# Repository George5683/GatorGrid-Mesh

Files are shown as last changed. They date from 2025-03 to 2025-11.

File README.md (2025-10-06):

# GatorGrid

GatorGrid is a multifunctional software solution designed for the Raspberry Pi Pico W by UF students to create a mesh network with wireless communication. It provides a low-cost, open-source alternative to existing mesh network solutions like ESP-WIFI-MESH and Zigbee by enabling seamless Wi-Fi-based communication between multiple nodes. The design uses two Pico W's per node in the network The project aims to ensure reliable message relay, even in case of node failures, making it ideal for individuals and organizations needing decentralized communication in remote or disaster-affected areas. GatorGrid focuses on accessibility, scalability, and real-time data transmission.

## Features
- MeshNode library for STA and AP mode
- Doxygen for documentation
- SPI interaction for internode communication
- Kicad Custom PCB deisgn with external battery charging capabilities

## Requirements to run
- Install doxygen
- Install graphviz
- Install extensions for VS code if applicable: Doxygen Documentation Generator 

## How to run Doxygen
1. Use doxygen Doxyfile to generate the documentation
2. Use **start doc\html\index.html** (WINDOWS ONLY) or **open doc/html/index.html** (LINUX/MAC)

## How to upload code to PICO W's
1. Push the bootsel and plug the microcontroller into the computer
2. Create the .uf2 file and upload it to PICO W by dragging it into the directory

## Bugs:
- At the moment if in an environment with high congestion, packets may not arrive. Moving locations is required.
- SPI has a slight delay of 110 ms per message sent. 

## Author
George Salomon, Cole Smith, Jonathon Brown, Mateo Slivka, Maxwell Evans

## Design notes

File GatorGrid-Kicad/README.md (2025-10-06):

## Kicad Designs

Design are separated into versions based on functionality and Design stages 

*Starting from BETA BUILD the first design V(X.0) is always the dev kit with extra Pico pinouts sockets for monitoring*

# Kicad Stages      
- INITIAL BUILD (V0.1 & V1.0)
- ALPHA BUILD (V2.0+)
- BETA BUILD (V3.0+)
- FINAL BUILD (V4.0+)

# External Sensor
At the moment the external sensor list is limited but can be expanded as needed
- DHT11 external PCB extension

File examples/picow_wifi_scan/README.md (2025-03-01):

# Driver Embedded Lab

This project integrates the LIS3DH accelerometer with a NeoMatrix LED display on a Raspberry Pi Pico W. It reads acceleration data and visually represents the movement using LEDs along with indicating when level.

## Features
- Reads acceleration data from the LIS3DH sensor.
- Controls a NeoMatrix LED display 
- Level program

## Run
1. Unzip the folder:
   ```sh
   unzip level.zip
   ```
2. Change the directory to the driver folder:
    ```sh
   cd /driver
   ```
3. Build the project using CMake:
    ```sh
   mkdir build && cd build
   cmake ..
   make
   ```
4. Flash the compiled binary to the Raspberry Pi Pico W.

## Functions Overview

### **LIS3DH**

### `LIS3DH()`
Constructor that initializes the x, y, and z values to 0

### `init()`
Initializes the accelerometer.

### `set_reg(uint8_t reg, uint8_t val)`
Set a register to a specific value

### `read_reg(uint8_t reg)`
read a register and output the value

### `update()`
Updates the x, y, and z values in the class with the accelerometer values.

### **NeoMatrix**

### `NeoMatrix(uint8_t width, uint8_t height)`
Constructor to set the width and height of the matrix

### `init()`
Initialize the NeoMatrix to get ready to shine

### `set_pixel(uint8_t row, uint8_t col, uint32_t color)`
set a pixel, within the 2D vector buffer in the class, to a specific color

### `clear_pixels()`
clear the pixels in the buffer

### `write()`
write the buffer data to the Matrix

### `urgb_u32(uint8_t r, uint8_t g, uint8_t b)`
Helper function to convert the values to a 32 bit value

## Author
George Salomon

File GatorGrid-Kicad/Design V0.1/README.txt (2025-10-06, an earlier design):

## Kicad Design V0.1
Explanation for the Pinouts on the Pico W:

- GPIO 1-22 and 26-28 are as the schematic states
- VBUS is 5V when connected to micro usb to power the Pico
- VSYS can power the Pico with ~1.8-5.5V input

TIPS:
- For adding a secondary power source, you need a schottky diode on the VSYS

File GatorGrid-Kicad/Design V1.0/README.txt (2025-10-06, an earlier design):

# Kicad Design V1.0

## Explanation for the Pinouts on the Pico W:

- GPIO 1-22 and 26-28 are as the schematic states
- VBUS is 5V when connected to micro usb to power the Pico
- VSYS can power the Pico with ~1.8-5.5V input

## Schematic Update:
- Added a JST connector for an extenal battery to be connected
- Added a switch after the JSt conncector for powering the Picos
- Added a polyfuse (polyfuse's reset instead of replacing the fuse if its broken)
- Added a Schottky diode (to prevent current backflow and if user connects the battery backwards)
- Added a charging/safety cicuit [TP4056] (for charging the battery and battery management)

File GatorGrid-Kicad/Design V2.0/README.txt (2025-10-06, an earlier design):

# Kicad Design V2.0

## Explanation for the Pinouts on the Pico W:

- GPIO 1-22 and 26-28 are as the schematic states
- VBUS is 5V when connected to micro usb to power the Pico
- VSYS can power the Pico with ~1.8-5.5V input

## Schematic Update:
- Fixed wiring of temp on the TP4056 as it was disconnected which casued the battery to not charge. 
- Changed POWER LED to be driven by two transistors which allows it to turn on when both picos are on. 
- Removed the schottky diode connected to the battery and instead put a diode on each VSYS out from each pico in order to prevent backflow when eitehr are plugged in as VSYS can be input and output. 
- Reworked Wiring on PCB

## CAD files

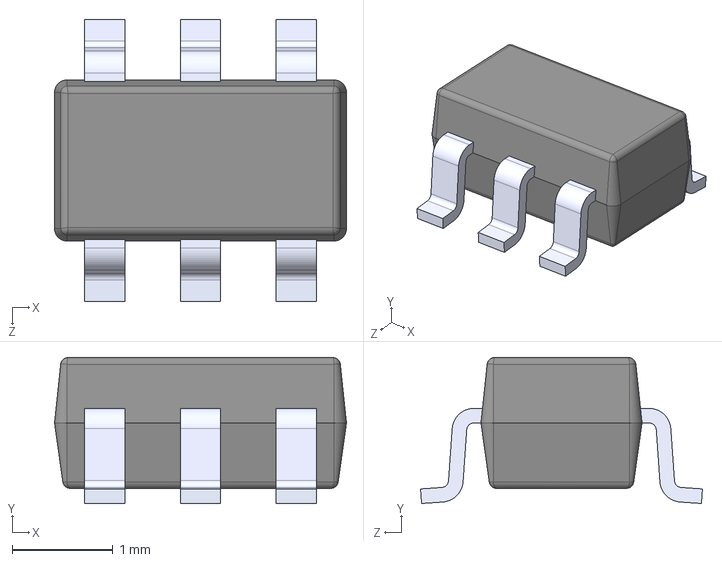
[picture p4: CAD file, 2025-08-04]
GatorGrid-Kicad/Design V4.0/Resources/MT3608/MT3608.step
2.90 x 1.45 x 2.80 mm

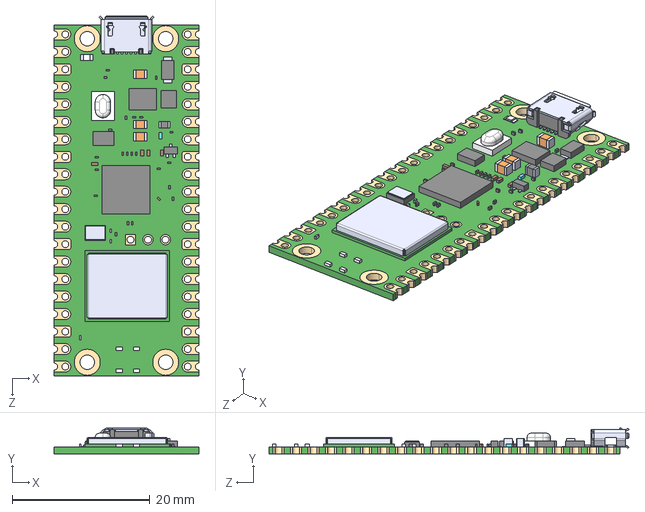
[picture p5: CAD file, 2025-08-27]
GatorGrid-Kicad/Design V4.0/Resources/RASPBERRY_PI_PICO_W(NH)/RASPBERRY_PI_PICO_W.step
21.0 x 3.73 x 52.3 mm

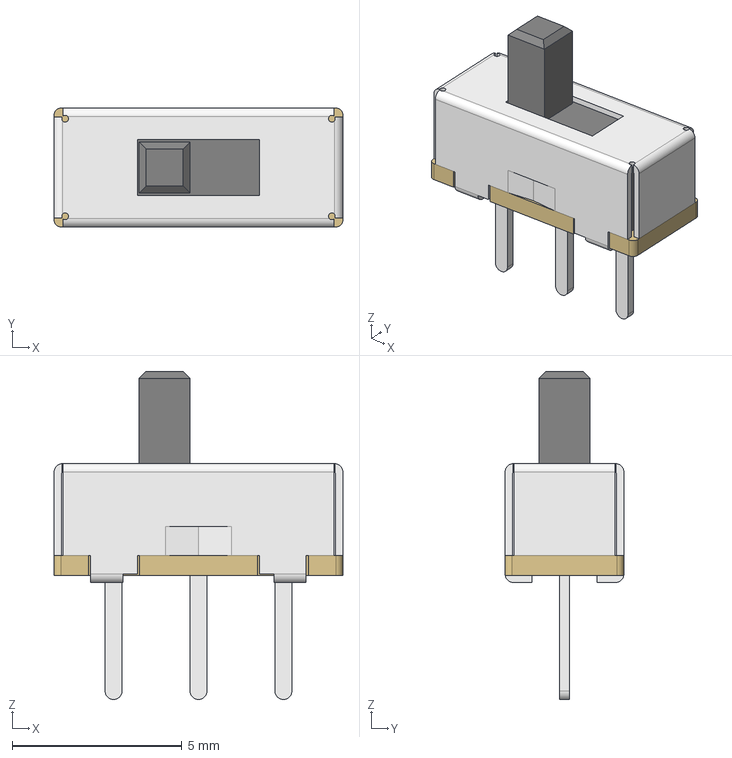
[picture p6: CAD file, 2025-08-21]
GatorGrid-Kicad/Design V4.0/Resources/SS12D00/SPDT slide switch SS12D00.step
8.50 x 3.50 x 9.66 mm

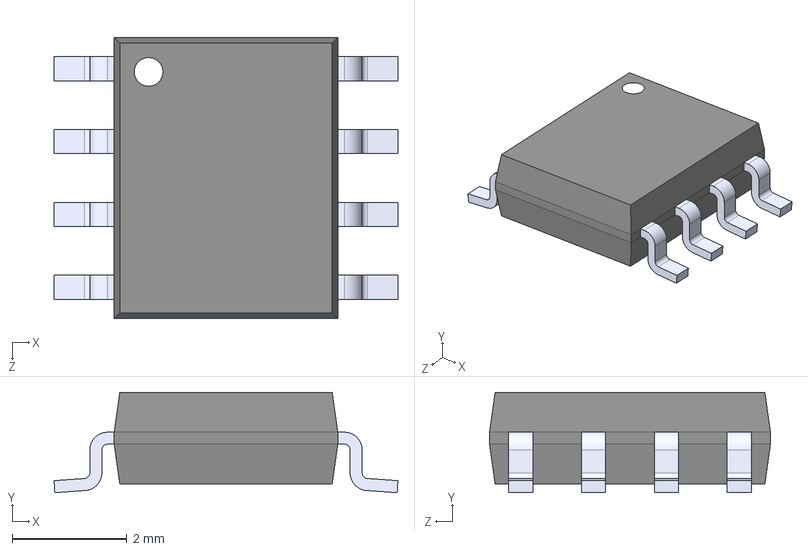
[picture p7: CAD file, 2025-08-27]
GatorGrid-Kicad/Design V4.0/Resources/TP4056/TP4056.step
6.00 x 1.75 x 4.90 mm

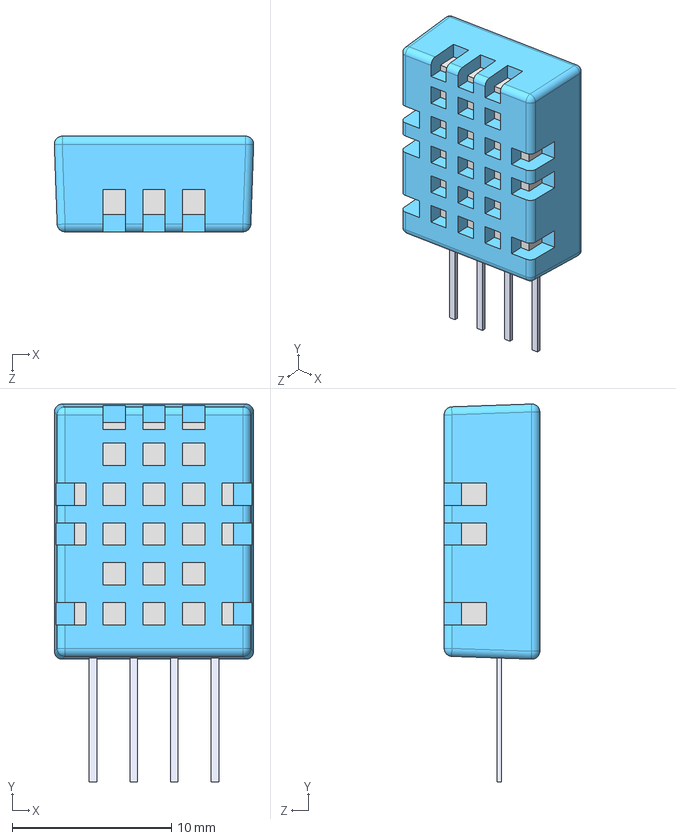
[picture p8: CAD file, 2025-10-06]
GatorGrid-Kicad/External-Sensor/Resources/DHT11/DHT11.step
12.5 x 23.7 x 6.00 mm

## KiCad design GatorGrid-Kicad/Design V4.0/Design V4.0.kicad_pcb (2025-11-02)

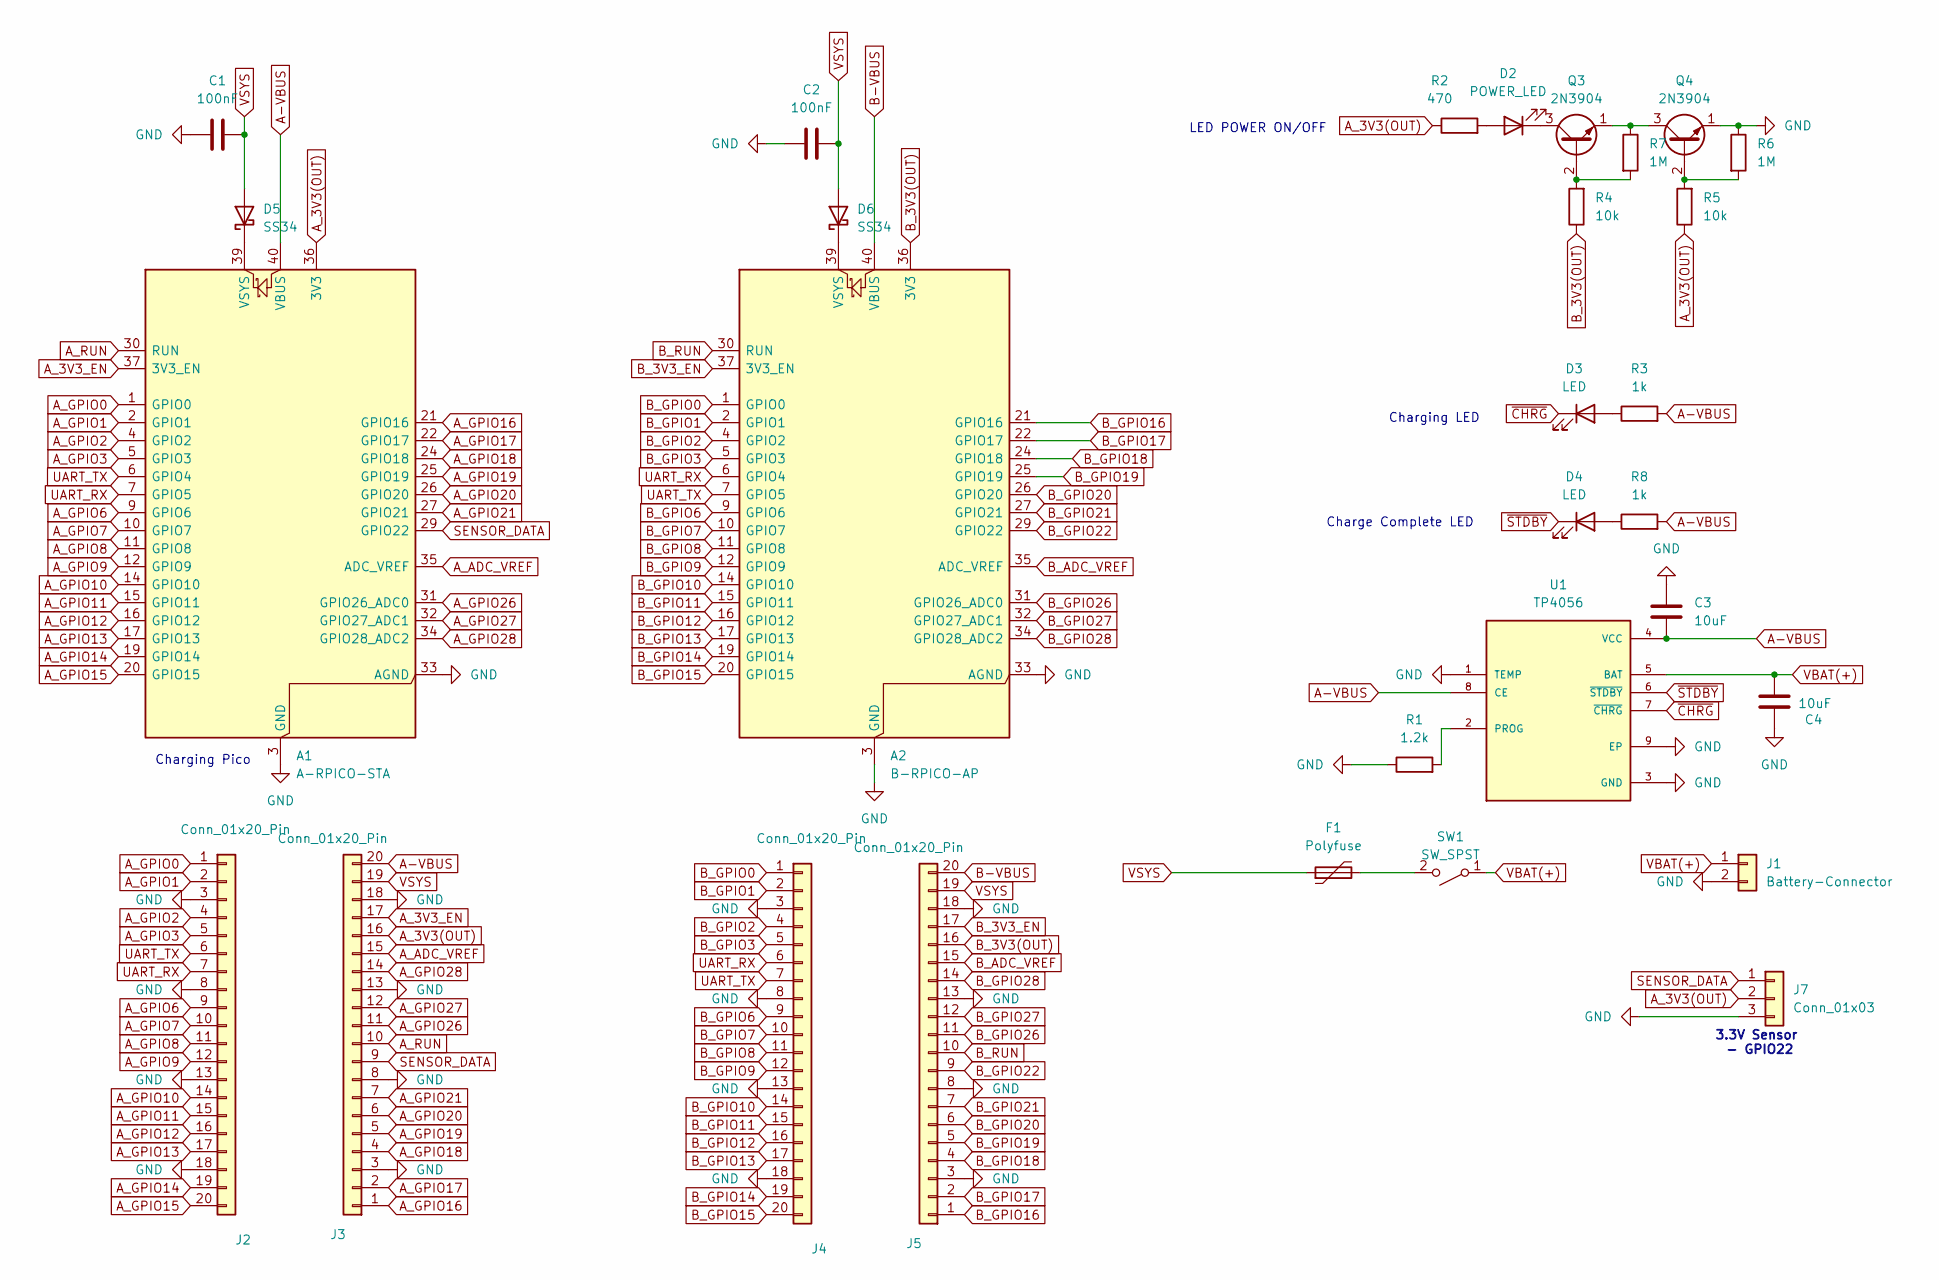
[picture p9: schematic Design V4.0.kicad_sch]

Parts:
A1: A-RPICO-STA; RaspberryPi_Pico_Common_THT
A2: B-RPICO-AP; RaspberryPi_Pico_Common_THT
C1, C2: 100nF; C_Disc_D5.0mm_W2.5mm_P2.50mm
C3, C4: 10uF; C_Radial_D5.0mm_H11.0mm_P2.00mm
D2: POWER_LED; LED_D5.0mm
D3, D4: LED; LED_D5.0mm
D5, D6: SS34; D_DO-41_SOD81_P7.62mm_Horizontal
F1: Polyfuse; Fuse_BelFuse_0ZRE0005FF_L8.3mm_W3.8mm
J1: Battery-Connector; JST_PH_S2B-PH-K_1x02_P2.00mm_Horizontal
J2, J3, J4, J5: Conn_01x20_Pin; PinSocket_1x20_P2.54mm_Vertical
J7: Conn_01x03; JST_XH_S3B-XH-A_1x03_P2.50mm_Horizontal
Q3, Q4: 2N3904; TO-92_Inline
R1: 1.2k; R_Axial_DIN0207_L6.3mm_D2.5mm_P7.62mm_Horizontal
R2: 470; R_Axial_DIN0207_L6.3mm_D2.5mm_P7.62mm_Horizontal
R3, R8: 1k; R_Axial_DIN0207_L6.3mm_D2.5mm_P7.62mm_Horizontal
R4, R5: 10k; R_Axial_DIN0207_L6.3mm_D2.5mm_P7.62mm_Horizontal
R6, R7: 1M; R_Axial_DIN0207_L6.3mm_D2.5mm_P7.62mm_Horizontal
SW1: SW_SPST; SW_Slide_SPDT_Angled_CK_OS102011MA1Q
U1: TP4056; SOP127P600X175-9N

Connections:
A-VBUS: A1.40 (VBUS), C3.2, J3.20, R3.2, R8.2, U1.4 (VCC), U1.8 (CE)
A_3V3(OUT): A1.36 (3V3), J3.16, J7.2, R2.1, R5.1
A_3V3_EN: A1.37 (3V3_EN), J3.17
A_ADC_VREF: A1.35 (ADC_VREF), J3.15
A_GPIO0: A1.1 (GPIO0), J2.1
A_GPIO1: A1.2 (GPIO1), J2.2
A_GPIO2: A1.4 (GPIO2), J2.4
A_GPIO3: A1.5 (GPIO3), J2.5
A_GPIO6: A1.9 (GPIO6), J2.9
A_GPIO7: A1.10 (GPIO7), J2.10
A_GPIO8: A1.11 (GPIO8), J2.11
A_GPIO9: A1.12 (GPIO9), J2.12
A_GPIO10: A1.14 (GPIO10), J2.14
A_GPIO11: A1.15 (GPIO11), J2.15
A_GPIO12: A1.16 (GPIO12), J2.16
A_GPIO13: A1.17 (GPIO13), J2.17
A_GPIO14: A1.19 (GPIO14), J2.19
A_GPIO15: A1.20 (GPIO15), J2.20
A_GPIO16: A1.21 (GPIO16), J3.1
A_GPIO17: A1.22 (GPIO17), J3.2
A_GPIO18: A1.24 (GPIO18), J3.4
A_GPIO19: A1.25 (GPIO19), J3.5
A_GPIO20: A1.26 (GPIO20), J3.6
A_GPIO21: A1.27 (GPIO21), J3.7
A_GPIO26: A1.31 (GPIO26_ADC0), J3.11
A_GPIO27: A1.32 (GPIO27_ADC1), J3.12
A_GPIO28: A1.34 (GPIO28_ADC2), J3.14
A_RUN: A1.30 (RUN), J3.10
B-VBUS: A2.40 (VBUS), J5.20
B_3V3(OUT): A2.36 (3V3), J5.16, R4.1
B_3V3_EN: A2.37 (3V3_EN), J5.17
B_ADC_VREF: A2.35 (ADC_VREF), J5.15
B_GPIO0: A2.1 (GPIO0), J4.1
B_GPIO1: A2.2 (GPIO1), J4.2
B_GPIO2: A2.4 (GPIO2), J4.4
B_GPIO3: A2.5 (GPIO3), J4.5
B_GPIO6: A2.9 (GPIO6), J4.9
B_GPIO7: A2.10 (GPIO7), J4.10
B_GPIO8: A2.11 (GPIO8), J4.11
B_GPIO9: A2.12 (GPIO9), J4.12
B_GPIO10: A2.14 (GPIO10), J4.14
B_GPIO11: A2.15 (GPIO11), J4.15
B_GPIO12: A2.16 (GPIO12), J4.16
B_GPIO13: A2.17 (GPIO13), J4.17
B_GPIO14: A2.19 (GPIO14), J4.19
B_GPIO15: A2.20 (GPIO15), J4.20
B_GPIO16: A2.21 (GPIO16), J5.1
B_GPIO17: A2.22 (GPIO17), J5.2
B_GPIO18: A2.24 (GPIO18), J5.4
B_GPIO19: A2.25 (GPIO19), J5.5
B_GPIO20: A2.26 (GPIO20), J5.6
B_GPIO21: A2.27 (GPIO21), J5.7
B_GPIO22: A2.29 (GPIO22), J5.9
B_GPIO26: A2.31 (GPIO26_ADC0), J5.11
B_GPIO27: A2.32 (GPIO27_ADC1), J5.12
B_GPIO28: A2.34 (GPIO28_ADC2), J5.14
B_RUN: A2.30 (RUN), J5.10
GND: A1.3 (GND), A1.8 (GND), A1.13 (GND), A1.18 (GND), A1.23 (GND), A1.28 (GND), A1.33 (AGND), A1.38 (GND), A2.3 (GND), A2.8 (GND), A2.13 (GND), A2.18 (GND), A2.23 (GND), A2.28 (GND), A2.33 (AGND), A2.38 (GND), C1.2, C2.1, C3.1, C4.1, J1.2, J2.3, J2.8, J2.13, J2.18, J3.3, J3.8, J3.13, J3.18, J4.3, J4.8, J4.13, J4.18, J5.3, J5.8, J5.13, J5.18, J7.3, Q4.1 (E), R1.1, R6.1, U1.1 (TEMP), U1.3 (GND), U1.9 (EP)
unnamed: A1.39 (VSYS), D5.1 (K)
unnamed: A2.39 (VSYS), D6.1 (K)
unnamed: D2.2 (A), R2.2
unnamed: D2.1 (K), Q3.3 (C)
unnamed: D3.2 (A), R3.1
unnamed: D4.2 (A), R8.1
unnamed: Q3.2 (B), R4.2, R7.2
unnamed: Q3.1 (E), Q4.3 (C), R7.1
unnamed: Q4.2 (B), R5.2, R6.2
unnamed: F1.2, SW1.2 (B)
unnamed: R1.2, U1.2 (PROG)
SENSOR_DATA: A1.29 (GPIO22), J3.9, J7.1
UART_RX: A1.7 (GPIO5), A2.6 (GPIO4), J2.7, J4.6
UART_TX: A1.6 (GPIO4), A2.7 (GPIO5), J2.6, J4.7
VBAT(+): C4.2, J1.1, SW1.1 (A), U1.5 (BAT)
VSYS: C1.1, C2.2, D5.2 (A), D6.2 (A), F1.1, J3.19, J5.19
~CHRG: D3.1 (K), U1.7 (~CHRG)
~STDBY: D4.1 (K), U1.6 (~STDBY)

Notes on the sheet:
Charging Pico
Charge Complete LED
3.3V Sensor - GPIO22
LED POWER ON/OFF
Charging LED

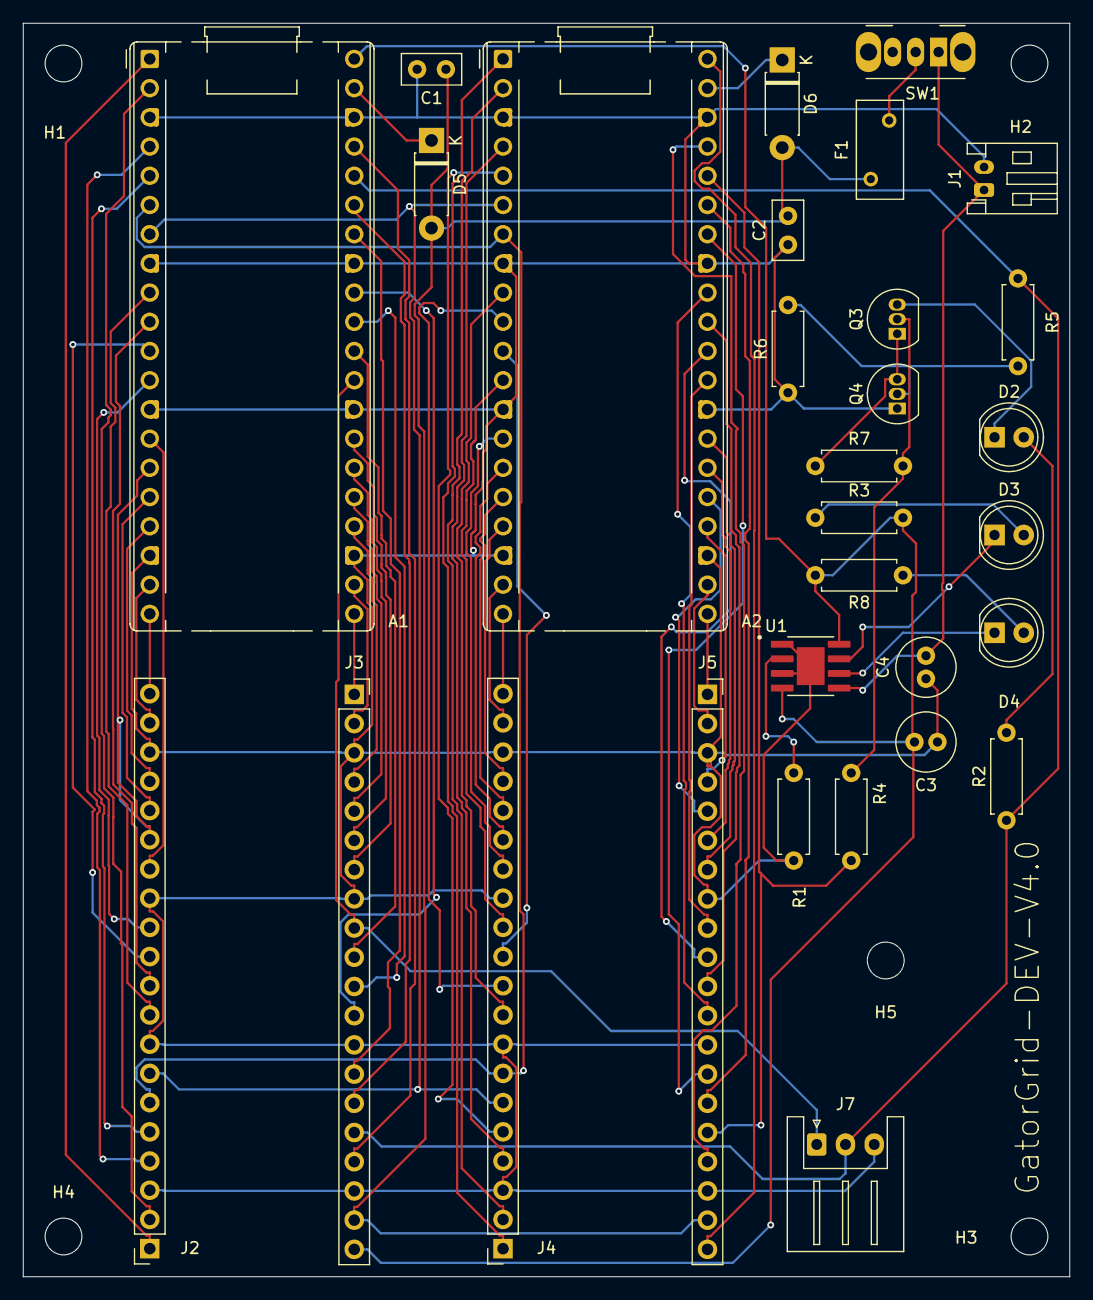
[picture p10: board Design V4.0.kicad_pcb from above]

Board: 2 copper layers, 91.0 x 109.0 mm, 35 parts (0 on the bottom side), 76 nets.

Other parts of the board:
H1, H2, H3, H4, H5: MountingHole_3.2mm_M3_ISO7380

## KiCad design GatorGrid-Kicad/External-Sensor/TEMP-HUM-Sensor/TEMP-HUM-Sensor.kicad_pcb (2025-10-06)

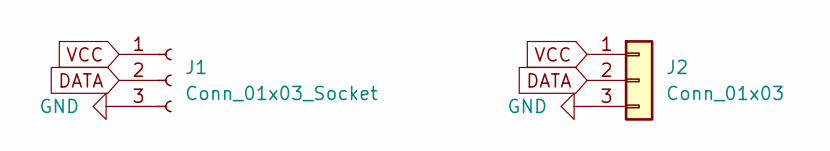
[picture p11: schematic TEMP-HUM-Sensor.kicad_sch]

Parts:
J1: Conn_01x03_Socket; PinSocket_1x03_P2.54mm_Vertical
J2: Conn_01x03; JST_XH_S3B-XH-A_1x03_P2.50mm_Horizontal

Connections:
DATA: J1.2, J2.2
GND: J1.3, J2.3
VCC: J1.1, J2.1

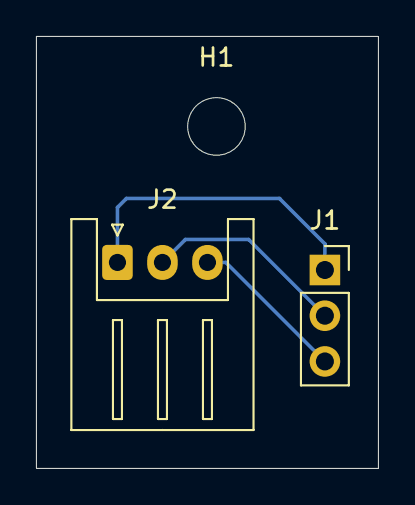
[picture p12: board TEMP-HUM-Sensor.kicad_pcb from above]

Board: 2 copper layers, 19.0 x 24.0 mm, 3 parts (0 on the bottom side), 3 nets.

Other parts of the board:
H1: MountingHole_3.2mm_M3_ISO7380

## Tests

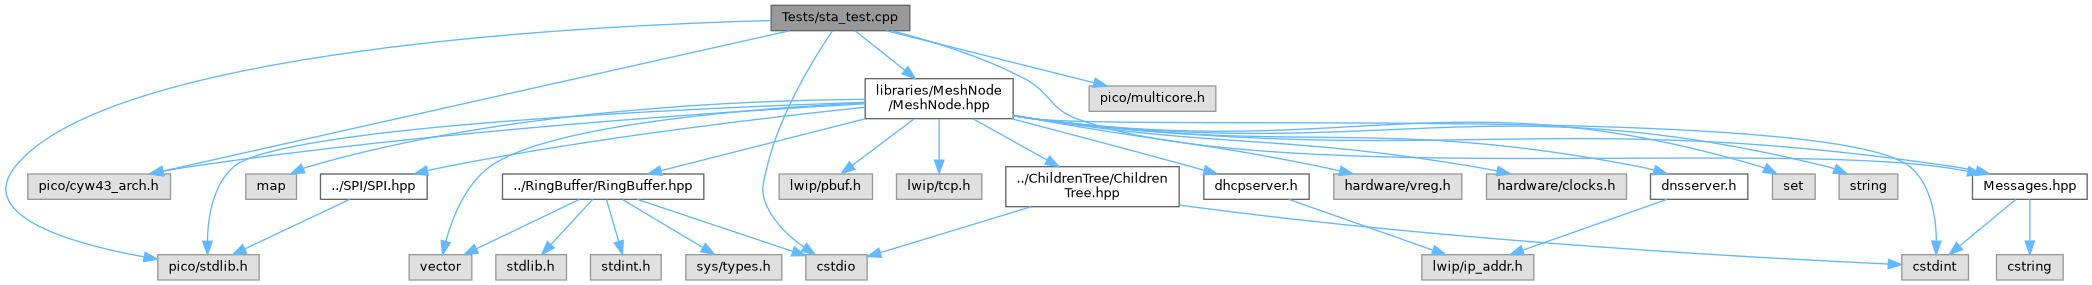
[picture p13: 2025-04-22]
docs/html/sta__test_8cpp__incl.png

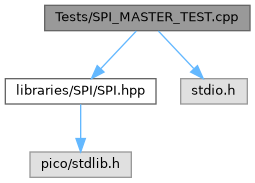
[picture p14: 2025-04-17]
docs/html/SPI__MASTER__TEST_8cpp__incl.png

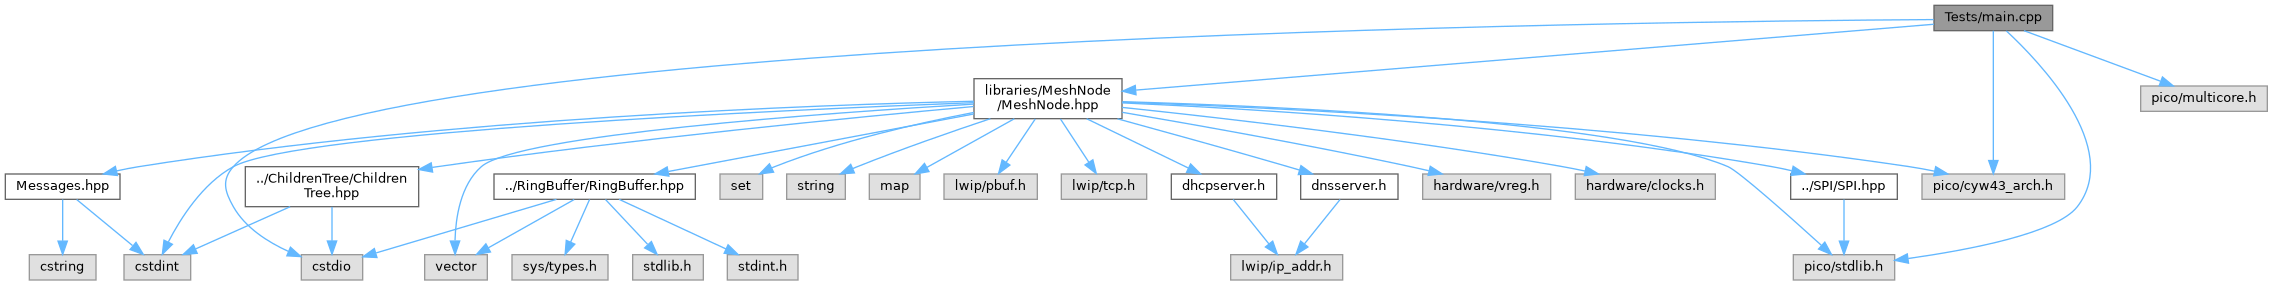
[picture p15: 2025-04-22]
docs/html/Tests_2main_8cpp__incl.png

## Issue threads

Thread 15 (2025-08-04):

Kicad PCB UPDATE

George5683, 2025-08-04:
- Need a boost converter module (MT3608)
- Battery connector JST
- Fuse {between the battery positive and the TP4056
- switch for powering on and off
- add capacitors on the boost converter output (Vout and GND)

George5683, 2025-08-11:
Decided to remove the boost converter and power the Picos using the VSYS line instead of the VBUS.

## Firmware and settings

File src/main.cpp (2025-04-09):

#include "pico/stdlib.h"
#include "libraries/MeshNode/MeshNode.hpp"
#include <cstdio>
#include "pico/cyw43_arch.h"

int main() {
    // Initialize stdio for debugging
    stdio_init_all();
    
    // Create the APNode object
    APNode node;
    //STANode node;

    //node.set_node_id(2);

    sleep_ms(5000);
        /*
    printf("Starting STA Mode\n");
    node.init_sta_mode();
    int err;
    err = node.connect_to_AP(ssid, pass, 10000);
    
    if(0 < err)
    {
        while(true) {
            printf("Wifi Error: %d\n", err);
            sleep_ms(1000);
            break;
        }
    }

    printf("Connected! Running Client Test\n");

    node.init_tcp();
    node.client_test();
    */
    

        
    // Initialize hardware and resources
    if (!node.init_ap_mode()) {
        printf("Failed to initialize MeshNode\n");
        return 1;
    }

    //node.set_ap_credentials(NULL, pass);
    
    // Configure AP (optional - uses defaults if not set)
    // defaults are below
    //node.set_ap_credentials("mesh_network", "password123");

    // Start AP mode
    if (!node.start_ap_mode()) {
        while(true) {
            printf("Failed to start AP mode\n");
            sleep_ms(1000);
        }
    }

    sleep_ms(5000);

    printf("Starting server test\n");

    node.server_start();

    while(node.server_running()) {
        printf("Server running, doing stuff...\n");
    }

    sleep_ms(5000);
    
    printf("MeshNode AP started with ID: %d\n", node.get_node_id());
    // Main loop
    while (true) {
        printf("Server over.\n");
        sleep_ms(1000);
        // Poll for network events
        //node.poll(1000);  // Poll with 1000ms timeout
    }


    return 0;
}

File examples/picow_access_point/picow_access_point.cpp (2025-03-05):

/**
 * Copyright (c) 2022 Raspberry Pi (Trading) Ltd.
 *
 * SPDX-License-Identifier: BSD-3-Clause
 */
extern "C" {
    #include "pico/cyw43_arch.h"
    #include "pico/stdlib.h"
    
    #include "lwip/pbuf.h"
    #include "lwip/tcp.h"
    
    #include "dhcpserver.h"
    #include "dnsserver.h"
}

 #include <string.h>
 
 #define TCP_PORT 80
 #define DEBUG_printf printf
 #define POLL_TIME_S 5
 #define HTTP_GET "GET"
 #define HTTP_RESPONSE_HEADERS "HTTP/1.1 %d OK\nContent-Length: %d\nContent-Type: text/html; charset=utf-8\nConnection: close\n\n"
 #define LED_TEST_BODY "<html><body><h1>Hello from Pico.</h1><p>Led is %s</p><p><a href=\"?led=%d\">Turn led %s</a></body></html>"
 #define LED_PARAM "led=%d"
 #define LED_TEST "/ledtest"
 #define LED_GPIO 0
 #define HTTP_RESPONSE_REDIRECT "HTTP/1.1 302 Redirect\nLocation: http://%s" LED_TEST "\n\n"
 
 typedef struct TCP_SERVER_T_ {
     struct tcp_pcb *server_pcb;
     bool complete;
     ip_addr_t gw;
 } TCP_SERVER_T;
 
 typedef struct TCP_CONNECT_STATE_T_ {
     struct tcp_pcb *pcb;
     int sent_len;
     char headers[128];
     char result[256];
     int header_len;
     int result_len;
     ip_addr_t *gw;
 } TCP_CONNECT_STATE_T;
 
 static err_t tcp_close_client_connection(TCP_CONNECT_STATE_T *con_state, struct tcp_pcb *client_pcb, err_t close_err) {
     if (client_pcb) {
         assert(con_state && con_state->pcb == client_pcb);
         tcp_arg(client_pcb, NULL);
         tcp_poll(client_pcb, NULL, 0);
         tcp_sent(client_pcb, NULL);
         tcp_recv(client_pcb, NULL);
         tcp_err(client_pcb, NULL);
         err_t err = tcp_close(client_pcb);
         if (err != ERR_OK) {
             DEBUG_printf("close failed %d, calling abort\n", err);
             tcp_abort(client_pcb);
             close_err = ERR_ABRT;
         }
         if (con_state) {
             free(con_state);
         }
     }
     return close_err;
 }
 
 static void tcp_server_close(TCP_SERVER_T *state) {
     if (state->server_pcb) {
         tcp_arg(state->server_pcb, NULL);
         tcp_close(state->server_pcb);
         state->server_pcb = NULL;
     }
 }
 
 static err_t tcp_server_sent(void *arg, struct tcp_pcb *pcb, u16_t len) {
     TCP_CONNECT_STATE_T *con_state = (TCP_CONNECT_STATE_T*)arg;
     DEBUG_printf("tcp_server_sent %u\n", len);
     con_state->sent_len += len;
     if (con_state->sent_len >= con_state->header_len + con_state->result_len) {
         DEBUG_printf("all done\n");
         return tcp_close_client_connection(con_state, pcb, ERR_OK);
     }
     return ERR_OK;
 }
 
 static int test_server_content(const char *request, const char *params, char *result, size_t max_result_len) {
     int len = 0;
     if (strncmp(request, LED_TEST, sizeof(LED_TEST) - 1) == 0) {
         // Get the state of the led
         bool value;
         cyw43_gpio_get(&cyw43_state, LED_GPIO, &value);
         int led_state = value;
 
         // See if the user changed it
         if (params) {
             int led_param = sscanf(params, LED_PARAM, &led_state);
             if (led_param == 1) {
                 if (led_state) {
                     // Turn led on
                     cyw43_gpio_set(&cyw43_state, LED_GPIO, true);
                 } else {
                     // Turn led off
                     cyw43_gpio_set(&cyw43_state, LED_GPIO, false);
                 }
             }
         }
         // Generate result
         if (led_state) {
             len = snprintf(result, max_result_len, LED_TEST_BODY, "ON", 0, "OFF");
         } else {
             len = snprintf(result, max_result_len, LED_TEST_BODY, "OFF", 1, "ON");
         }
     }
     return len;
 }
 
 err_t tcp_server_recv(void *arg, struct tcp_pcb *pcb, struct pbuf *p, err_t err) {
     TCP_CONNECT_STATE_T *con_state = (TCP_CONNECT_STATE_T*)arg;
     if (!p) {
         DEBUG_printf("connection closed\n");
         return tcp_close_client_connection(con_state, pcb, ERR_OK);
     }
     assert(con_state && con_state->pcb == pcb);
     if (p->tot_len > 0) {
         DEBUG_printf("tcp_server_recv %d err %d\n", p->tot_len, err);
 #if 0
         for (struct pbuf *q = p; q != NULL; q = q->next) {
             DEBUG_printf("in: %.*s\n", q->len, q->payload);
         }
 #endif
         // Copy the request into the buffer
         pbuf_copy_partial(p, con_state->headers, p->tot_len > sizeof(con_state->headers) - 1 ? sizeof(con_state->headers) - 1 : p->tot_len, 0);
 
         // Handle GET request
         if (strncmp(HTTP_GET, con_state->headers, sizeof(HTTP_GET) - 1) == 0) {
             char *request = con_state->headers + sizeof(HTTP_GET); // + space
             char *params = strchr(request, '?');
             if (params) {
                 if (*params) {
                     char *space = strchr(request, ' ');
                     *params++ = 0;
                     if (space) {
                         *space = 0;
                     }
                 } else {
                     params = NULL;
                 }
             }
 
             // Generate content
             con_state->result_len = test_server_content(request, params, con_state->result, sizeof(con_state->result));
             DEBUG_printf("Request: %s?%s\n", request, params);
             DEBUG_printf("Result: %d\n", con_state->result_len);
 
             // Check we had enough buffer space
             if (con_state->result_len > sizeof(con_state->result) - 1) {
                 DEBUG_printf("Too much result data %d\n", con_state->result_len);
                 return tcp_close_client_connection(con_state, pcb, ERR_CLSD);
             }
 
             // Generate web page
             if (con_state->result_len > 0) {
                 con_state->header_len = snprintf(con_state->headers, sizeof(con_state->headers), HTTP_RESPONSE_HEADERS,
                     200, con_state->result_len);
                 if (con_state->header_len > sizeof(con_state->headers) - 1) {
                     DEBUG_printf("Too much header data %d\n", con_state->header_len);
                     return tcp_close_client_connection(con_state, pcb, ERR_CLSD);
                 }
             } else {
                 // Send redirect
                 con_state->header_len = snprintf(con_state->headers, sizeof(con_state->headers), HTTP_RESPONSE_REDIRECT,
                     ipaddr_ntoa(con_state->gw));
                 DEBUG_printf("Sending redirect %s", con_state->headers);
             }
 
             // Send the headers to the client
             con_state->sent_len = 0;
             err_t err = tcp_write(pcb, con_state->headers, con_state->header_len, 0);
             if (err != ERR_OK) {
                 DEBUG_printf("failed to write header data %d\n", err);
                 return tcp_close_client_connection(con_state, pcb, err);
             }
 
             // Send the body to the client
             if (con_state->result_len) {
                 err = tcp_write(pcb, con_state->result, con_state->result_len, 0);
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

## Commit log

2025-03-05 Fixed structure of project
    [MeshNode.cpp, main.cpp, picow_access_point.cpp]
2025-03-19 Fixed memory leak issues and added sending a message for STA and receiving for AP
    [AP_Test.cpp, sta_test.cpp]
2025-04-03 BUG: SPI NOT WORKING WRITING AND READING
    [AP_Test.cpp, sta_test.cpp]
2025-04-08 added a delay in Master SPI to wait for the Slave to initialize
2025-04-08 added debug outputs for SPI
2025-04-08 Rework server loop framework for AP node, now the main loop has been pulled outside of server specific functions
    [main.cpp]
2025-04-08 Added is_read_available and is_write_available for SPI
2025-04-09 Added waiting for ACKs before sending next message - Removed free in ringbuffer insert
2025-04-09 added SPI to MESHNODE
2025-04-09 Testing merge between AP/STA and SPI
2025-04-09 Fix SPI init
2025-04-09 fixed bug for SPI sending ID
2025-04-17 spi and meshnode docs updated
2025-04-17 spi docs
2025-04-17 Design update
    [Design_V1.0.kicad_pcb]
2025-04-17 updates spi docs
2025-04-17 MPU Sensor Stuff
2025-04-18 refined Kicad
    [Design_V1.0.kicad_pcb, freerouting.dsn]
2025-04-18 add imu
2025-04-18 add i2c to sta_two
2025-08-04 added files for voltage booster
    [MT3608.step]
2025-08-11 added all the symbols
    [Design_V1.0.kicad_sch]
2025-08-13 updated the schematic to have no errors on the error check
    [Design_V1.0.kicad_sch]
2025-08-21 updated PCB
    [Design_V1.0.kicad_pcb, Design_V1.0.kicad_sch, SPDT slide switch SS12D00.step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]
2025-08-27 added V2
    [Design V2.0.kicad_pcb, Design V2.0.kicad_sch, Design_V1.0.kicad_pcb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]
2025-08-28 edited resistor values for the AND gate circuitry
    [Design V2.0.kicad_sch]
2025-08-28 Updating Kicad
2025-09-04 Minor changes to schematic
2025-10-06 Merge assist (#28)
    * Updated power management, channel usage and wpa protection for consistency testing
    * added comments
    * added comments
    * added cmake for SPI testing
    * Added wire tests
    * Updated SPI
    * Fixed Message passing within node
    * fixed connections
    * Reduced delay for SPI to start up
    * Update MeshNodeAP.cpp for new SPI
    * Update MeshNodeSTA.cpp for SPI
    * Update MeshNode.hpp to include SPI stuff
    * Update SPI.cpp minor changes
    * updating the bugs
    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
    [DHT11.step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]
2025-11-02 Kicad Final merge (#36)
    * Finished updating V4.0 schematic
    * Finished PCB design for V4.0
    * Moved around some components in the PCB
    * Finihsed design
    [Design V4-B_Cu.gbr, Design V4-B_Mask.gbr, Design V4-B_Paste.gbr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]
